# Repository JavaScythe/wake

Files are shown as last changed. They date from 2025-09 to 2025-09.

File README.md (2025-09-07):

The best alarm clock you'll ever meet.

An alexa without a microphone.

- 35 neopixels
- ESP32 with wifi
- Speaker
- Buzzer
- Projector





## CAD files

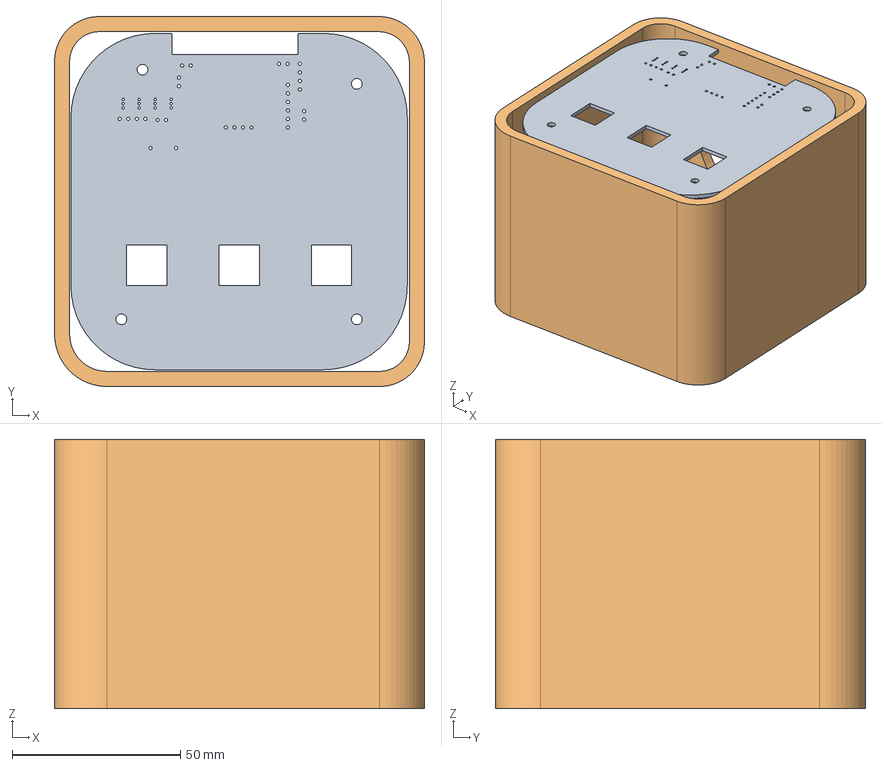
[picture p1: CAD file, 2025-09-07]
wakeshell.FCStd
110.0 x 110.0 x 80.0 mm
wake_PCB

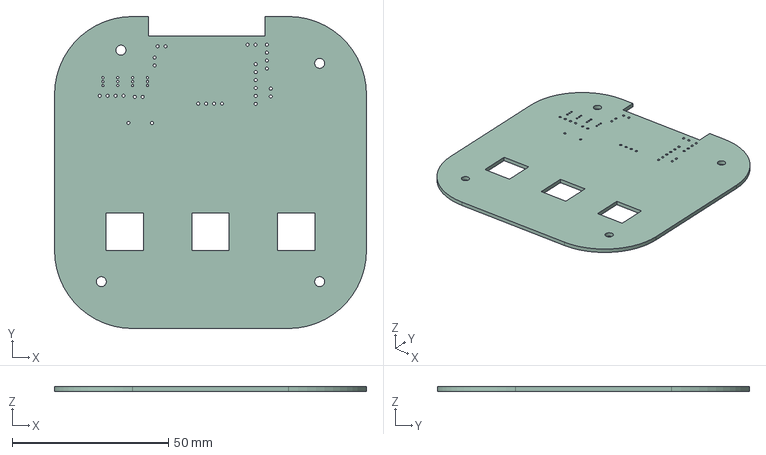
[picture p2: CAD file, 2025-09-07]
wake.step
100.0 x 100.0 x 1.51 mm

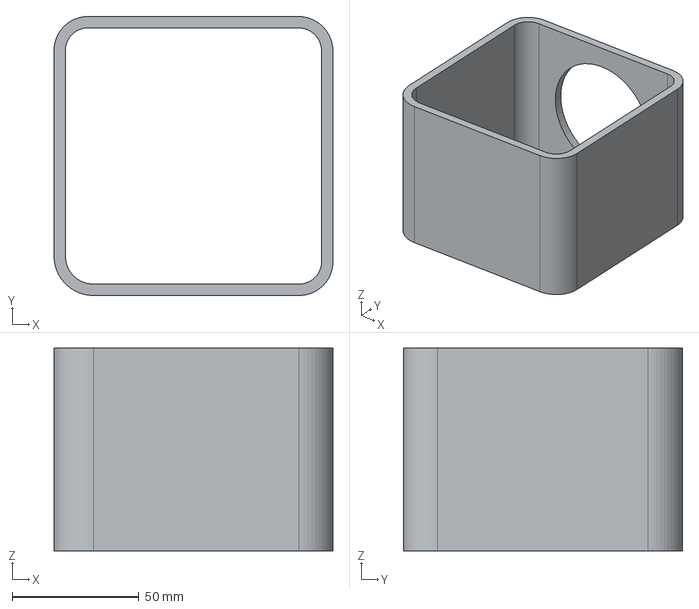
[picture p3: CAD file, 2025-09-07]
wakeshell-Body.step
110.0 x 110.0 x 80.0 mm

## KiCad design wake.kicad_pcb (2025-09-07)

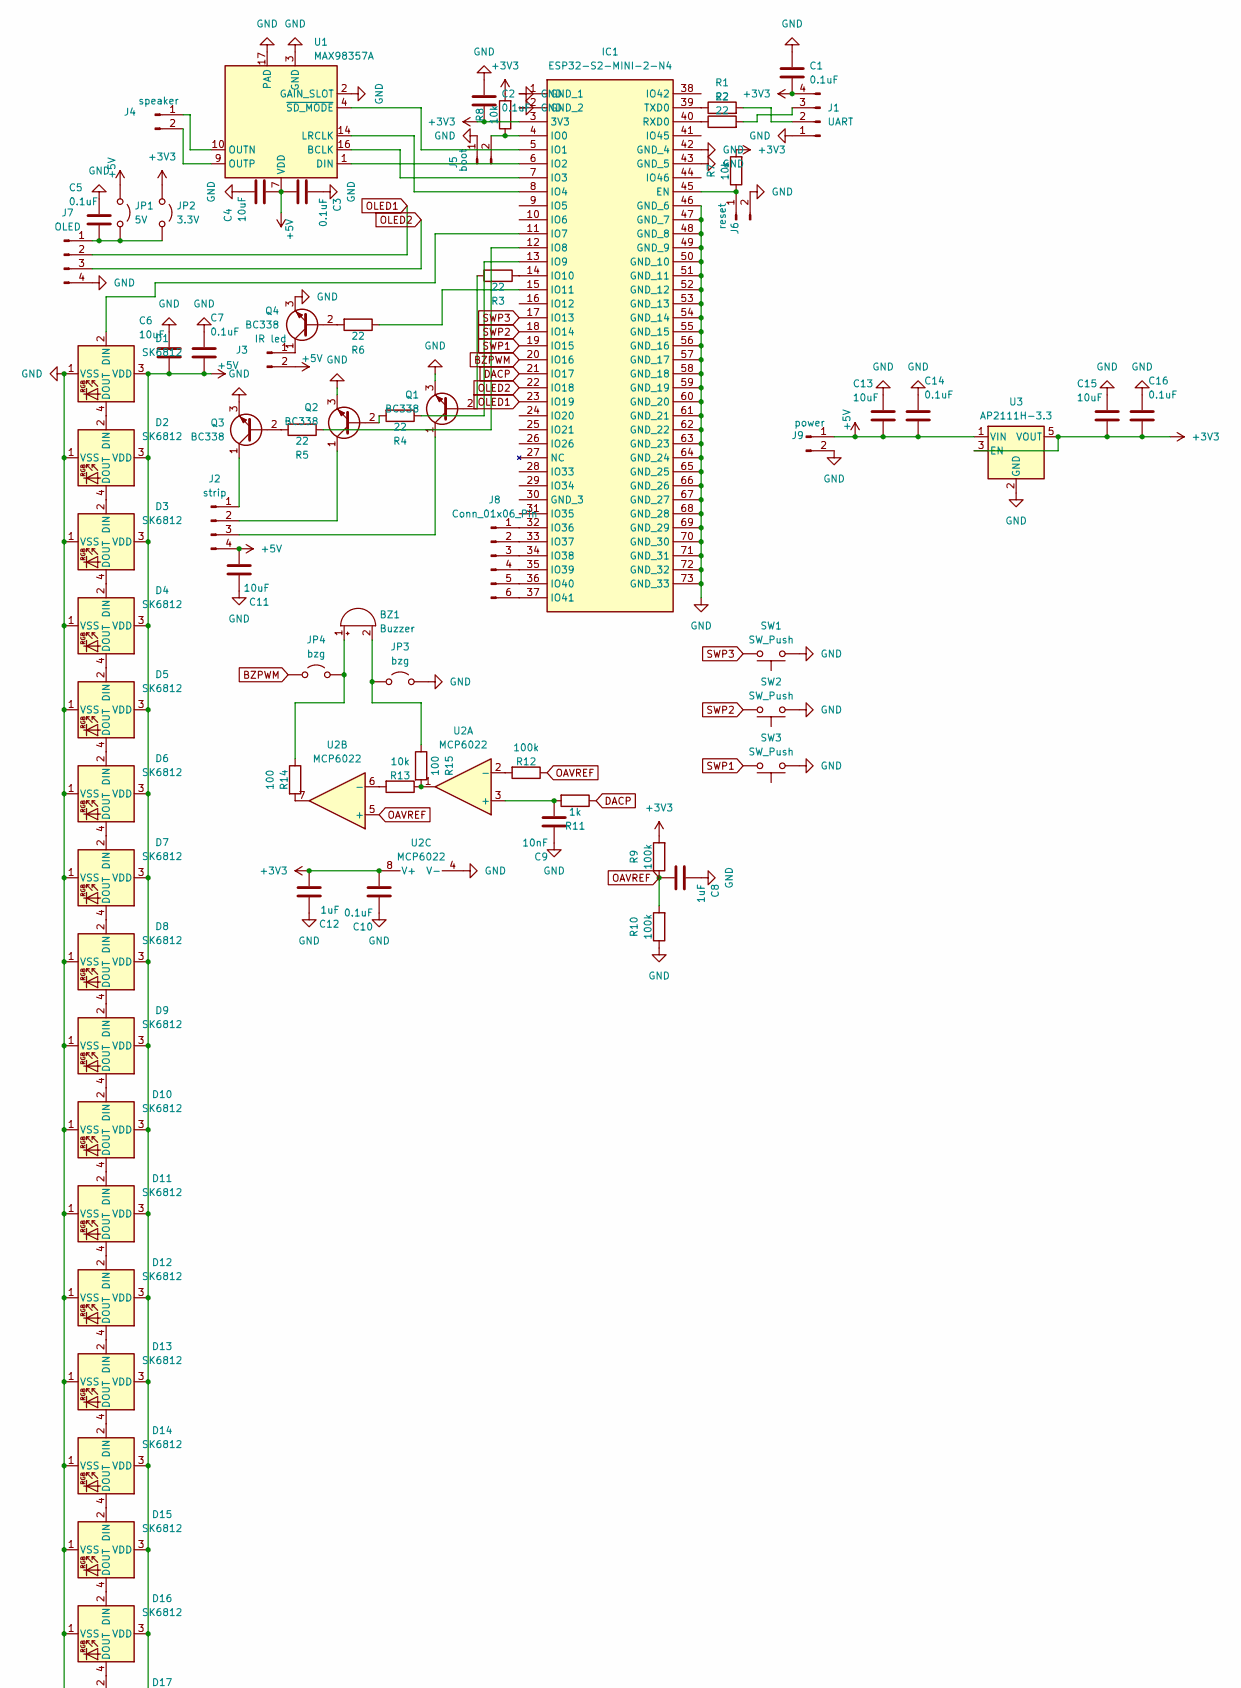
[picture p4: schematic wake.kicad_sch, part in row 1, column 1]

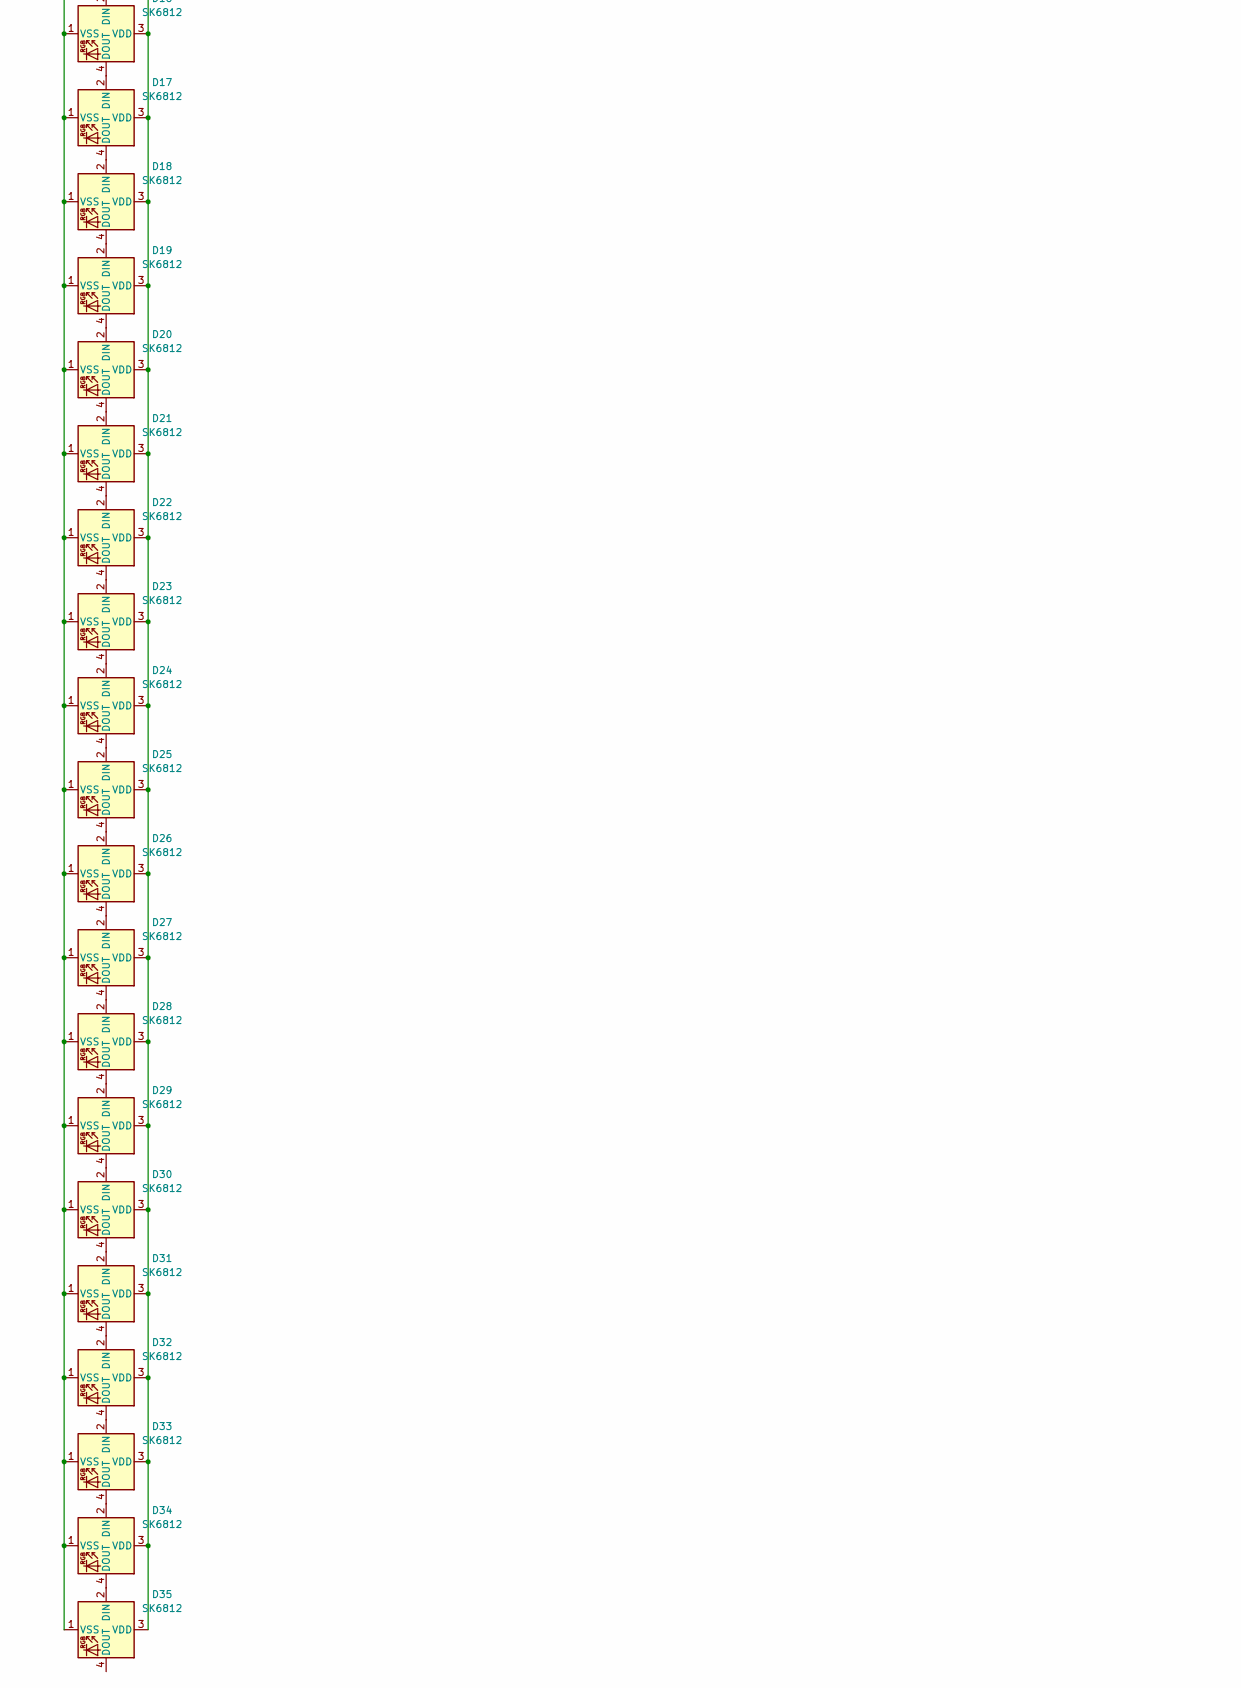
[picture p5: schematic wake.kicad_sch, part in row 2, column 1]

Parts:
BZ1: Buzzer; Buzzer_12x9.5RM7.6
C1, C2, C3, C5, C7, C10, C14, C16: 0.1uF; C_0402_1005Metric
C4, C6, C11, C13, C15: 10uF; C_0402_1005Metric
C8, C12: 1uF; C_0402_1005Metric
C9: 10nF; C_0402_1005Metric
D1, D2, D3, D4, D5, D6, D7, D8, D9, D10, D11, D12, D13, D14, D15, D16, D17, D18, D19, D20, D21, D22, D23, D24, D25, D26, D27, D28, D29, D30, D31, D32, D33, D34, D35: SK6812; LED_SK6812_PLCC4_5.0x5.0mm_P3.2mm
IC1: ESP32-S2-MINI-2-N4; ESP32S2MINI2N4; Mouser Part Number 356-ESP32MINI-2-N4
J1: UART; PinHeader_1x04_P2.54mm_Vertical
J2: strip; PinHeader_1x04_P2.54mm_Vertical
J3: IR led; PinHeader_1x02_P2.54mm_Vertical
J4: speaker; PinHeader_1x02_P2.54mm_Vertical
J5: boot; PinHeader_1x02_P2.54mm_Vertical
J6: reset; PinHeader_1x02_P2.54mm_Vertical
J7: OLED; PinHeader_1x04_P2.54mm_Vertical
J8: Conn_01x06_Pin; PinHeader_1x06_P2.54mm_Vertical
J9: power; PinHeader_1x02_P2.54mm_Vertical
JP1: 5V; SolderJumper-2_P1.3mm_Open_TrianglePad1.0x1.5mm
JP2: 3.3V; SolderJumper-2_P1.3mm_Open_TrianglePad1.0x1.5mm
JP3, JP4: bzg; SolderJumper-2_P1.3mm_Open_TrianglePad1.0x1.5mm
Q1, Q2, Q3, Q4: BC338; TO-92_Inline
R1, R2, R3, R4, R5, R6: 22; R_0402_1005Metric
R7, R8, R13: 10k; R_0402_1005Metric
R9, R10, R12: 100k; R_0402_1005Metric
R11: 1k; R_0402_1005Metric
R14, R15: 100; R_0402_1005Metric
SW1, SW2, SW3: SW_Push; SW-SMD_4P-L12.0-W12.0-P5.00-LS15.5
U1: MAX98357A; TQFN-16-1EP_3x3mm_P0.5mm_EP1.23x1.23mm
U2: MCP6022; SOP-8_3.9x4.9mm_P1.27mm
U3: AP2111H-3.3; SOT-223

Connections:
+3V3: C1.2, C2.2, C10.2, C12.2, C15.2, C16.2, IC1.3 (3V3), J1.4, JP2.1 (A), R7.2, R8.2, R9.2, U2.8 (V+), U3.3 (EN), U3.5 (VOUT)
+5V: C3.2, C4.2, C6.2, C7.2, C11.2, C13.2, C14.2, D1.3 (VDD), D2.3 (VDD), D3.3 (VDD), D4.3 (VDD), D5.3 (VDD), D6.3 (VDD), D7.3 (VDD), D8.3 (VDD), D9.3 (VDD), D10.3 (VDD), D11.3 (VDD), D12.3 (VDD), D13.3 (VDD), D14.3 (VDD), D15.3 (VDD), D16.3 (VDD), D17.3 (VDD), D18.3 (VDD), D19.3 (VDD), D20.3 (VDD), D21.3 (VDD), D22.3 (VDD), D23.3 (VDD), D24.3 (VDD), D25.3 (VDD), D26.3 (VDD), D27.3 (VDD), D28.3 (VDD), D29.3 (VDD), D30.3 (VDD), D31.3 (VDD), D32.3 (VDD), D33.3 (VDD), D34.3 (VDD), D35.3 (VDD), J2.4, J3.2, J9.1, JP1.1 (A), U1.7 (VDD), U1.8 (VDD), U3.1 (VIN)
BZPWM: IC1.20 (IO16), JP4.1 (A)
DACP: IC1.21 (IO17), R11.1
GND: C1.1, C2.1, C3.1, C4.1, C5.1, C6.1, C7.1, C8.1, C9.1, C10.1, C11.1, C12.1, C13.1, C14.1, C15.1, C16.1, D1.1 (VSS), D2.1 (VSS), D3.1 (VSS), D4.1 (VSS), D5.1 (VSS), D6.1 (VSS), D7.1 (VSS), D8.1 (VSS), D9.1 (VSS), D10.1 (VSS), D11.1 (VSS), D12.1 (VSS), D13.1 (VSS), D14.1 (VSS), D15.1 (VSS), D16.1 (VSS), D17.1 (VSS), D18.1 (VSS), D19.1 (VSS), D20.1 (VSS), D21.1 (VSS), D22.1 (VSS), D23.1 (VSS), D24.1 (VSS), D25.1 (VSS), D26.1 (VSS), D27.1 (VSS), D28.1 (VSS), D29.1 (VSS), D30.1 (VSS), D31.1 (VSS), D32.1 (VSS), D33.1 (VSS), D34.1 (VSS), D35.1 (VSS), IC1.1 (GND_1), IC1.2 (GND_2), IC1.42 (GND_4), IC1.43 (GND_5), IC1.46 (GND_6), IC1.47 (GND_7), IC1.48 (GND_8), IC1.49 (GND_9), IC1.50 (GND_10), IC1.51 (GND_11), IC1.52 (GND_12), IC1.53 (GND_13), IC1.54 (GND_14), IC1.55 (GND_15), IC1.56 (GND_16), IC1.57 (GND_17), IC1.58 (GND_18), IC1.59 (GND_19), IC1.60 (GND_20), IC1.61 (GND_21), IC1.62 (GND_22), IC1.63 (GND_23), IC1.64 (GND_24), IC1.65 (GND_25), IC1.66 (GND_26), IC1.67 (GND_27), IC1.68 (GND_28), IC1.69 (GND_29), IC1.70 (GND_30), IC1.71 (GND_31), IC1.72 (GND_32), IC1.73 (GND_33), J1.1, J5.1, J6.2, J7.4, J9.2, JP3.2 (B), Q1.3 (E), Q2.3 (E), Q3.3 (E), Q4.3 (E), R10.1, SW1.1, SW2.1, SW3.1, U1.2 (GAIN_SLOT), U1.3 (GND), U1.11 (GND), U1.15 (GND), U1.17 (PAD), U2.4 (V-), U3.2 (GND)
unnamed: BZ1.1 (+), JP4.2 (B), R14.1
unnamed: BZ1.2 (-), JP3.1 (A), R15.1
unnamed: D1.2 (DIN), IC1.11 (IO7)
unnamed: D1.4 (DOUT), D2.2 (DIN)
unnamed: D2.4 (DOUT), D3.2 (DIN)
unnamed: D3.4 (DOUT), D4.2 (DIN)
unnamed: D4.4 (DOUT), D5.2 (DIN)
unnamed: D5.4 (DOUT), D6.2 (DIN)
unnamed: D6.4 (DOUT), D7.2 (DIN)
unnamed: D7.4 (DOUT), D8.2 (DIN)
unnamed: D8.4 (DOUT), D9.2 (DIN)
unnamed: D9.4 (DOUT), D10.2 (DIN)
unnamed: D10.4 (DOUT), D11.2 (DIN)
unnamed: D11.4 (DOUT), D12.2 (DIN)
unnamed: D12.4 (DOUT), D13.2 (DIN)
unnamed: D13.4 (DOUT), D14.2 (DIN)
unnamed: D14.4 (DOUT), D15.2 (DIN)
unnamed: D15.4 (DOUT), D16.2 (DIN)
unnamed: D16.4 (DOUT), D17.2 (DIN)
unnamed: D17.4 (DOUT), D18.2 (DIN)
unnamed: D18.4 (DOUT), D19.2 (DIN)
unnamed: D19.4 (DOUT), D20.2 (DIN)
unnamed: D20.4 (DOUT), D21.2 (DIN)
unnamed: D21.4 (DOUT), D22.2 (DIN)
unnamed: D22.4 (DOUT), D23.2 (DIN)
unnamed: D23.4 (DOUT), D24.2 (DIN)
unnamed: D24.4 (DOUT), D25.2 (DIN)
unnamed: D25.4 (DOUT), D26.2 (DIN)
unnamed: D26.4 (DOUT), D27.2 (DIN)
unnamed: D27.4 (DOUT), D28.2 (DIN)
unnamed: D28.4 (DOUT), D29.2 (DIN)
unnamed: D29.4 (DOUT), D30.2 (DIN)
unnamed: D30.4 (DOUT), D31.2 (DIN)
unnamed: D31.4 (DOUT), D32.2 (DIN)
unnamed: D32.4 (DOUT), D33.2 (DIN)
unnamed: D33.4 (DOUT), D34.2 (DIN)
unnamed: D34.4 (DOUT), D35.2 (DIN)
unnamed: IC1.45 (EN), J6.1, R7.1
unnamed: IC1.4 (IO0), J5.2, R8.1
unnamed: IC1.5 (IO1), U1.4 (~SD_MODE)
unnamed: IC1.6 (IO2), U1.1 (DIN)
unnamed: IC1.7 (IO3), U1.16 (BCLK)
unnamed: IC1.8 (IO4), U1.14 (LRCLK)
unnamed: IC1.12 (IO8), R5.1
unnamed: IC1.13 (IO9), R4.1
unnamed: IC1.14 (IO10), R3.1
unnamed: IC1.15 (IO11), R6.1
unnamed: IC1.32 (IO36), J8.1
unnamed: IC1.33 (IO37), J8.2
unnamed: IC1.34 (IO38), J8.3
unnamed: IC1.35 (IO39), J8.4
unnamed: IC1.36 (IO40), J8.5
unnamed: IC1.37 (IO41), J8.6
unnamed: IC1.40 (RXD0), R2.1
unnamed: IC1.39 (TXD0), R1.1
unnamed: J1.2, R1.2
unnamed: J1.3, R2.2
unnamed: J2.1, Q3.1 (C)
unnamed: J2.2, Q2.1 (C)
unnamed: J2.3, Q1.1 (C)
unnamed: J3.1, Q4.1 (C)
unnamed: J4.1, U1.10 (OUTN)
unnamed: J4.2, U1.9 (OUTP)
unnamed: C5.2, J7.1, JP1.2 (B), JP2.2 (B)
unnamed: Q1.2 (B), R3.2
unnamed: Q2.2 (B), R4.2
unnamed: Q3.2 (B), R5.2
unnamed: Q4.2 (B), R6.2
unnamed: R13.1, R15.2, U2.1
unnamed: R14.2, U2.7
unnamed: C9.2, R11.2, U2.3 (+)
unnamed: R12.2, U2.2 (-)
unnamed: R13.2, U2.6 (-)
OAVREF: C8.2, R9.1, R10.2, R12.1, U2.5 (+)
OLED1: IC1.23 (IO19), J7.2
OLED2: IC1.22 (IO18), J7.3
SWP1: IC1.19 (IO15), SW3.2
SWP2: IC1.18 (IO14), SW2.2
SWP3: IC1.17 (IO13), SW1.2

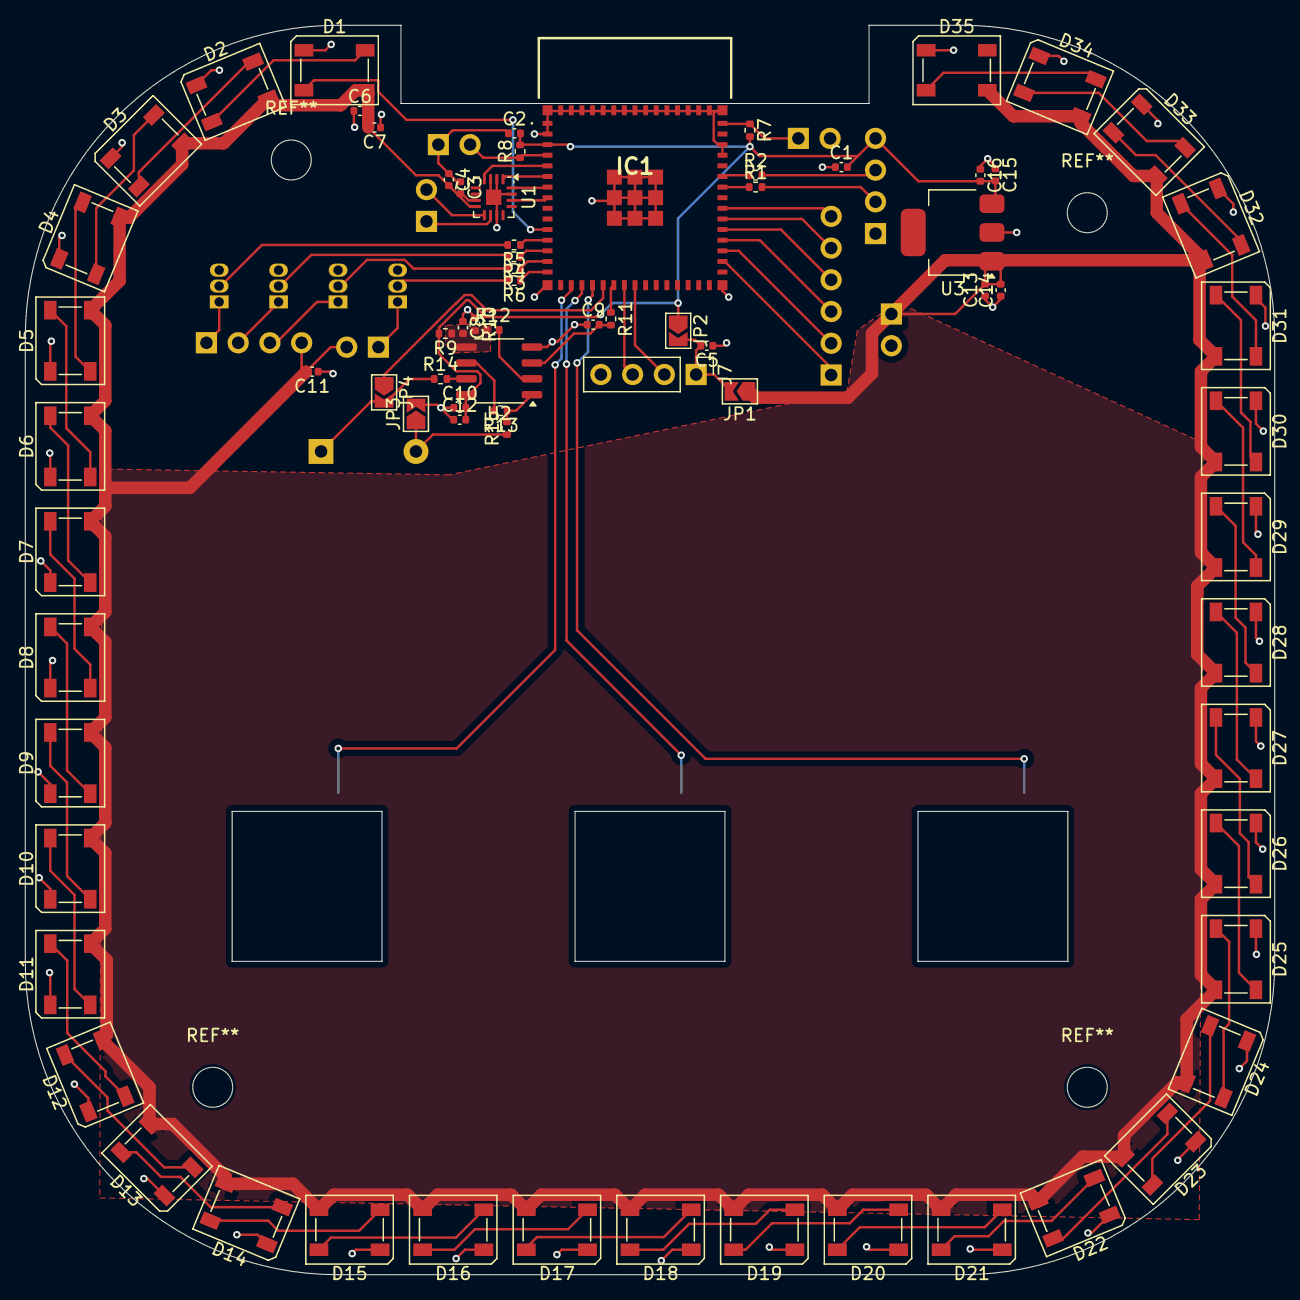
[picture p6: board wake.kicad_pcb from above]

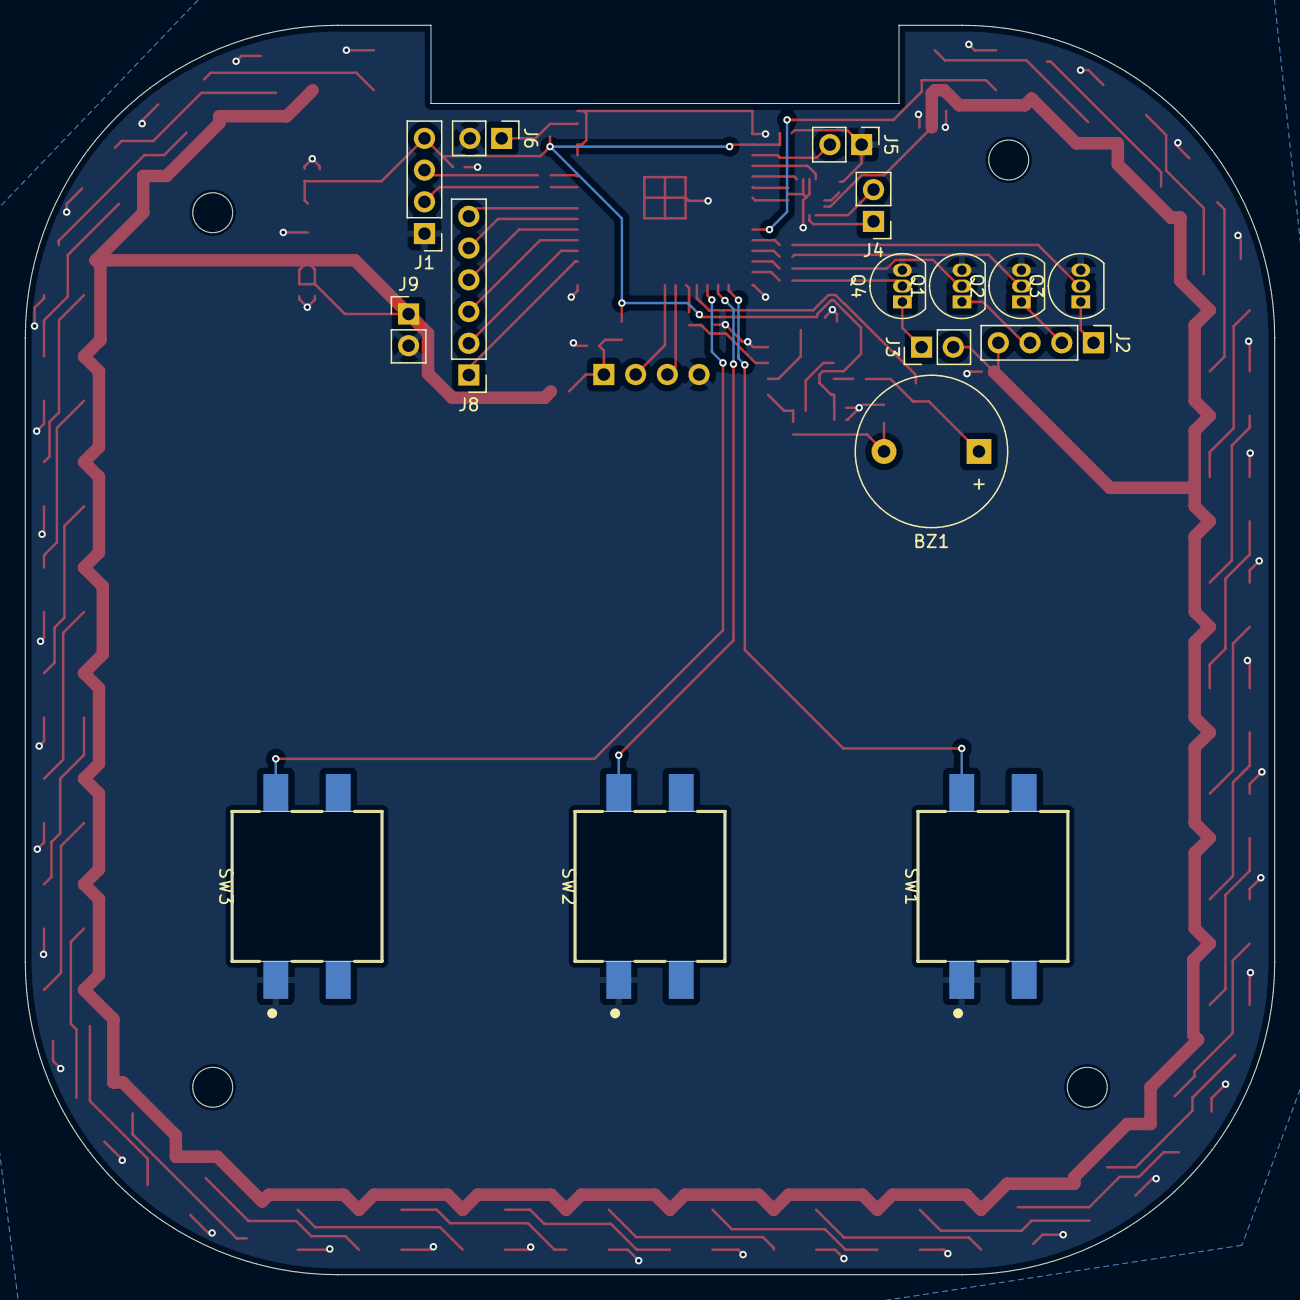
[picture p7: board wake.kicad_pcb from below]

Board: 2 copper layers, 100.0 x 100.0 mm, 91 parts (16 on the bottom side), 84 nets.

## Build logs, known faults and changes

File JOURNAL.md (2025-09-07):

Total 25 hours

## 8/20/25: Project inception
I looked at my cheap alarm clock and realized what a sad piece of e waste it was. It had functions for alarm and radio that are never used, and lost about 13 minutes over the last two years. I decided this would be no more.

One part I did like about the existing one was its ceiling projection. It projected a 8 segment display on the ceiling to show time. I quickly beat the brakes off this existing one and recovered the module. I discovered what appeared to be a four wire protocol + likely 5v for light, 3.3 for logic and ground of course.

I also wanted to drive both a buzzer and a small 3 inch speaker cone for fun/utility

2 Hours

## 8/21/25: Those who scope creep
The other inhabitant of my nightstand was next: my alexa. Used solely for alarms, it was a waste of bandwidth. It left its mark on this project though: I deciced to have the edge light up, just like its predecessor.

This presented a problem: how do I (oh by the way i chose cheapest esp32 for this project with pcb antenna) mount the esp32 on the edge for EMI but also mantain a ring of leds?

I chose some of the ICs like power and mcu

2 Hours

## 8/22/25: Schematic creation
In addtion to the lighting, I also have a LED strip controlled via breadboard on my nightstand. It would be easy to mount the mofsets in this board and have it control them instead. A fourth mofset is used to control a IR led to control a projector.



4 Hours

## 8/23/25: Schematic work
I settled on a semisquare layout. Not copying alexa, (bro there's no mic there's no assistant please no sue), and maxmimum perimeter for MOAR leds.

I also included a OLED for some insight as well as finding some buttons that would fit. Not sure how many I will put on.



4 Hours

## 8/24/25: Layout work
Finished the LEDS. very painful to do. I think I will do 3 buttons



2 Hours

## 8/25/25: Layout + Buzzer
I looked into implementing the buzzer. This was much harder than I though it would be. It's difficult to get a balance between cost, quality (audio) of implementation, and easy of development. For context I want variable frequency, not just a static tone.

NO picture i added like 3 symbols disconnected

2 Hours

## 8/26/25: Buzzer complete
Will be done with MCP6022. Here is the releveant scheamtic portion



1 Hour

## 8/27/25: Routing
Slow day in school = many hours of routing. This was a messy-ish board because of the mixed power, circular shape, and two layer. It should likely be fine... the router is very close by in the same room.



Additionally I flipped the button footprint so I could have their bodies inside the PCB for less height.. to make the buttons on par with the LEDS once I make case.

4 Hours

## 9/4/25: Hiatas and minor routing.

Fixed a few ratlines left on board. Added mounting holes for case design

1 Hour

## 9/6/25: Case and writeup

Designed the case for easy mounting. The buttons I will do some trial and error on, just a matter of some tweaks. Mount should be high enough to fit speaker.



3 Hours
